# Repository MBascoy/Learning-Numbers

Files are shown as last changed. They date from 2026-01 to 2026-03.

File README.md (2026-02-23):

# Learning Numbers
This is a little educational game for kids (around 3-5 years old) to learn numbers and counting.

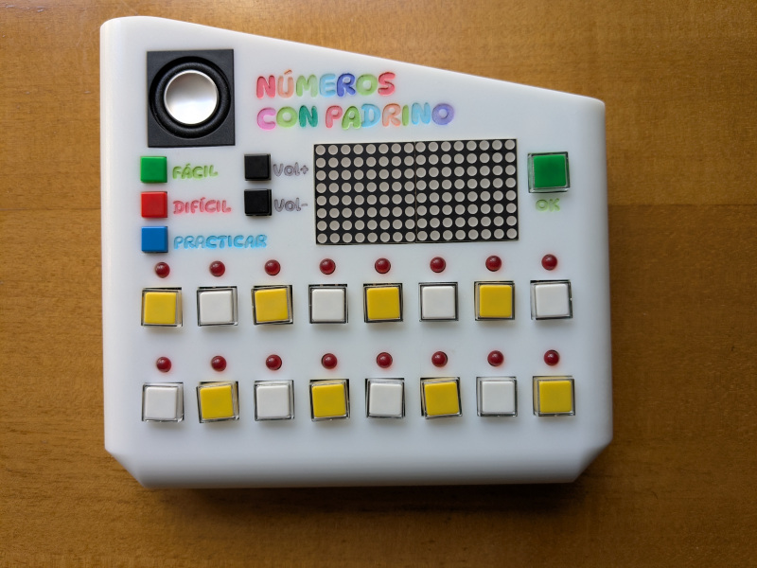
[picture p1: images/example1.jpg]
example1

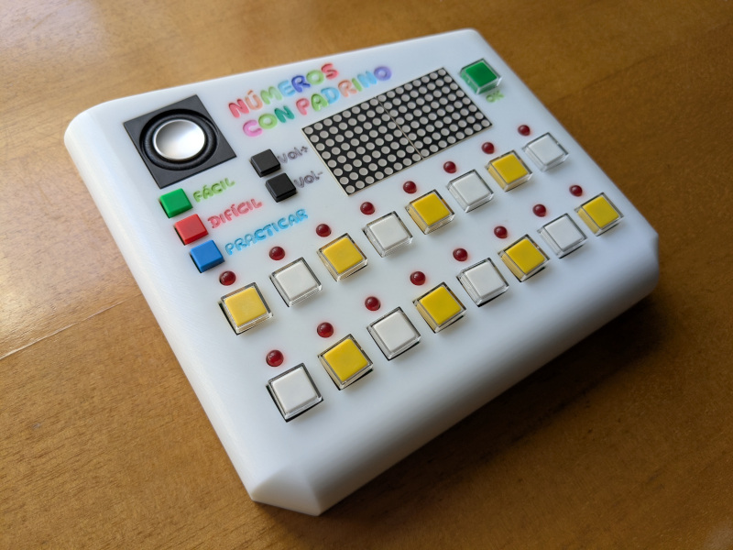
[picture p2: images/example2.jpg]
example2

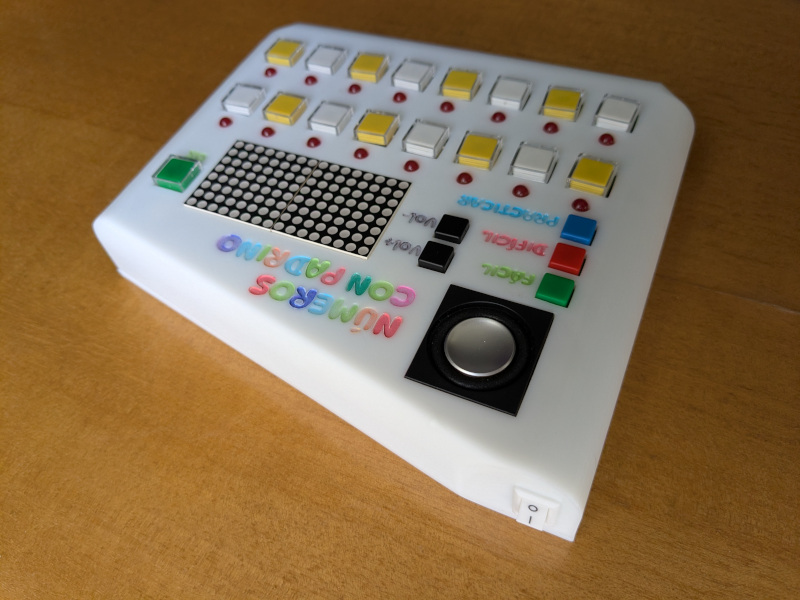
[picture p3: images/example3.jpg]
example3

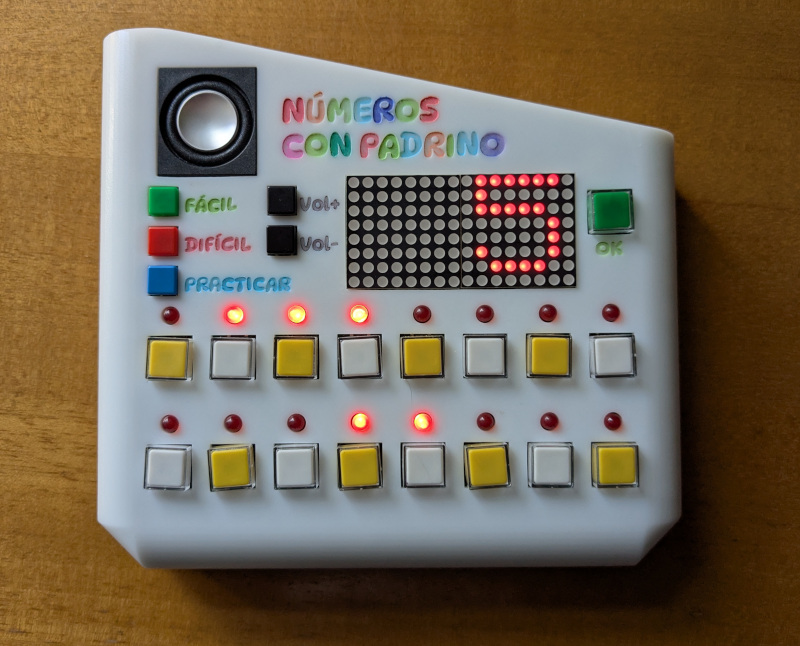
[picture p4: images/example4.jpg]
example4

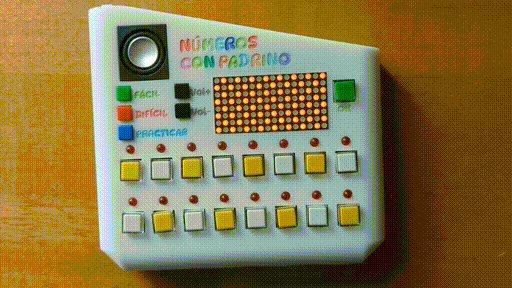
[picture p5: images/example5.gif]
example5


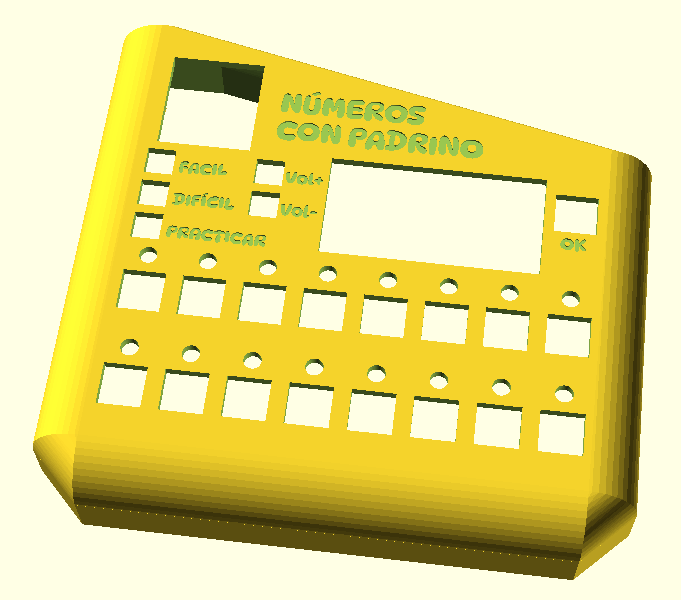
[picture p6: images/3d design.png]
3d design

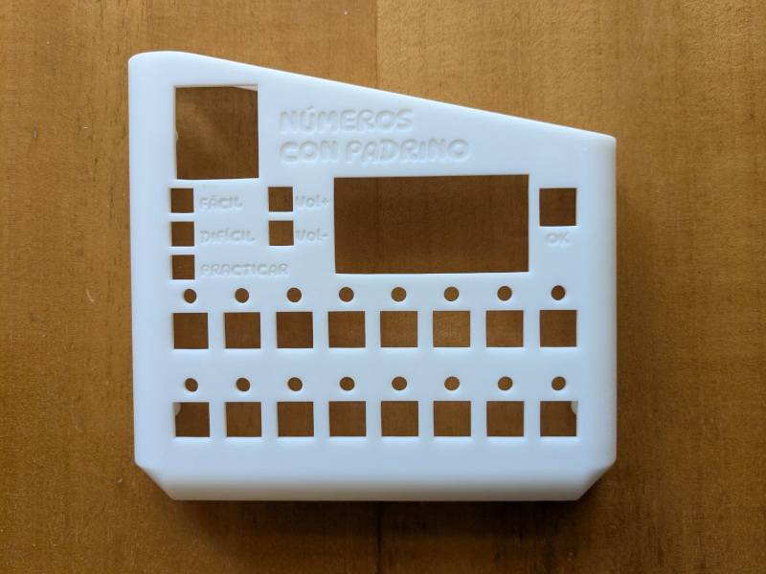
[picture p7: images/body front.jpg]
body front

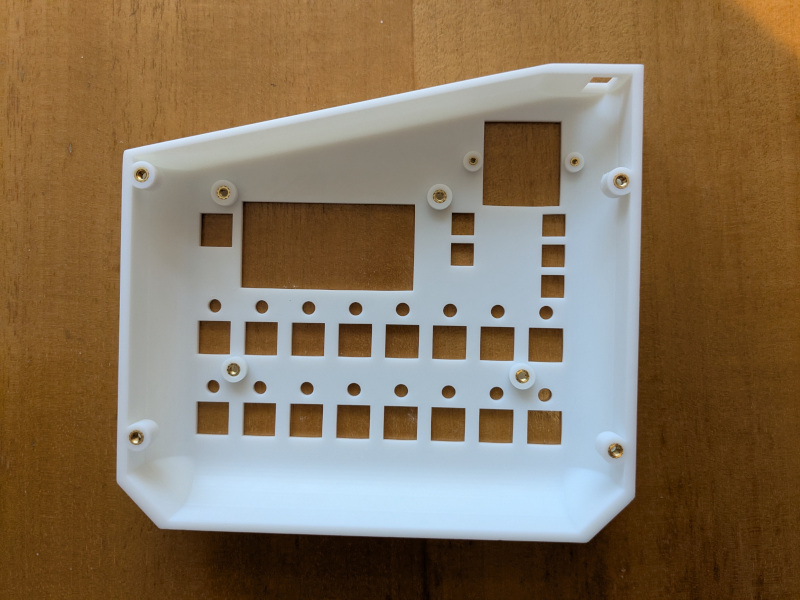
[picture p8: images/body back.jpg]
body back

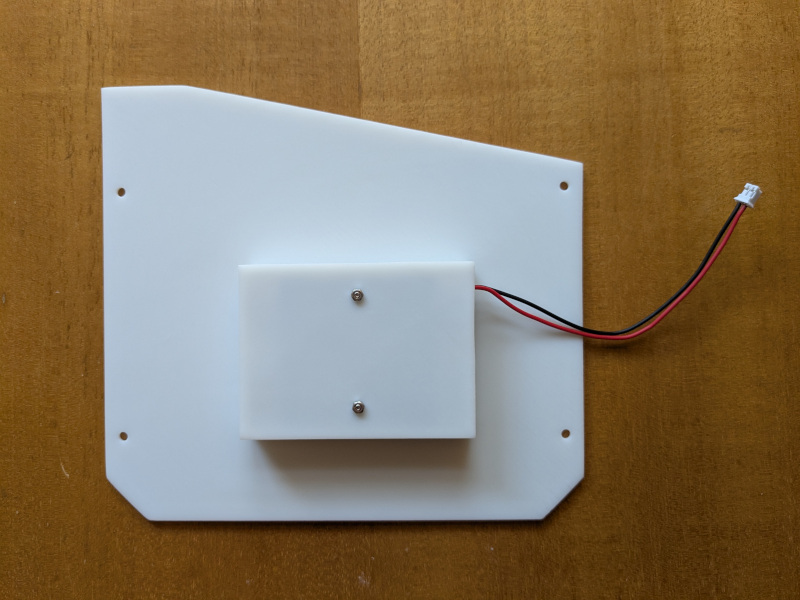
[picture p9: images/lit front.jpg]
lit front

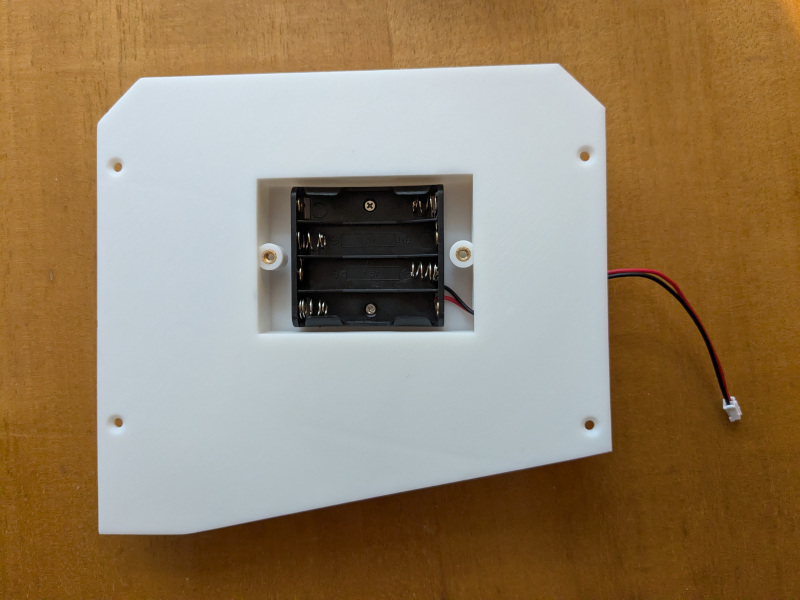
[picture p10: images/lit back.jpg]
lit back


## How to play
The game has 3 modes:
- Easy Mode
- Hard Mode
- Practice Mode

In **Easy Mode** the game displays a random number between 1 and 5, you have to use the two button rows on the bottom to turn on the lights to match the number diplayed (eg: if a 3 is shown you have to press 3 buttons to turn on 3 lights), after that you press "**OK**", if the result is correct you will see a "happy face" and a new number will be shown, if the result is incorrect you will see a "sad face" and you have to correct your answer and try it again.

**Hard Mode** is the same as easy but with numbers between 6 and 16.

In **Practice Mode** the game just show how many lights are on, so you can see which number relates to how many lights are on, (eg: if you turn on 2 lights the display will show you a 2), if you press "**OK**" the game will play an audio of the number that is displayed in the screen.

## How to build
You have to do 3 things:
- Make the 3D design
- Make the PCB (And solder all the components)
- Flash a microcontroller with the code

The components list is the following:

(All the components can be found in Aliexpress)

- 2x matrix led 8x8
- 1x Atmega168pa
- 5x 74HC595 chips
- 2x 74HC165 chips
- 16x 5mm Leds
- 1x 8Mhz crystal oscillator
- 33x 1K resistors
- 16x 10K resistors
- 1x 1Ohm resistor
- 2x 22pf smd capacitors
- 1x 100nf smd capacitor
- 1x 470uf electrolitic capacitor
- 17x SMD Push buttons 12mm
- 5x SMD Push buttons 6mm
- 1x ZIF socket 28pin narrow
- 1x Power switch
- 3x JST connector ph2.0
- 1x battery holder 4x AAA
- 2x Screw M2 inserts (3mm height, 3mm OD)
- 4x M2 Screws
- 2x M2 Nuts
- 6x Screw M3 inserts (5mm height, 5mm OD)
- 4x Screw M3 inserts (3mm height, 5mm OD)
- 8x M3 Screws
- 1x DFPlayer mini
- 1x Speaker 3W 4Ohm PH2.0 terminal

For the **speaker** you need this specific model:

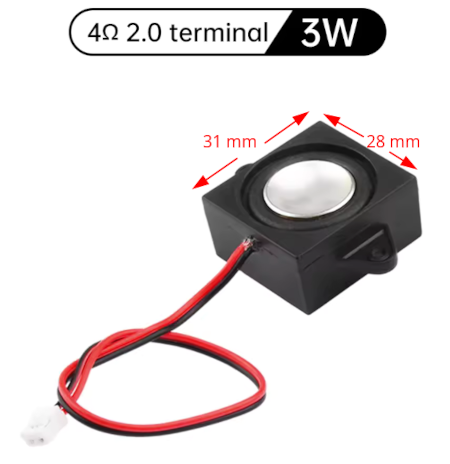
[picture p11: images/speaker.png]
Speaker


For the **power switch** you need this specific model:

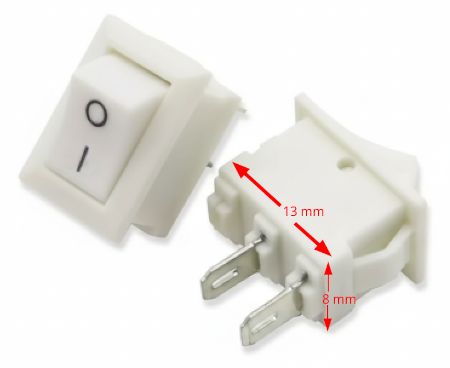
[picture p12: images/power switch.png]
Power switch


You need to add a JST connector (PH 2.0) to the power switch and the battery holder, this is an image of the power switch with the PH 2.0 connector:

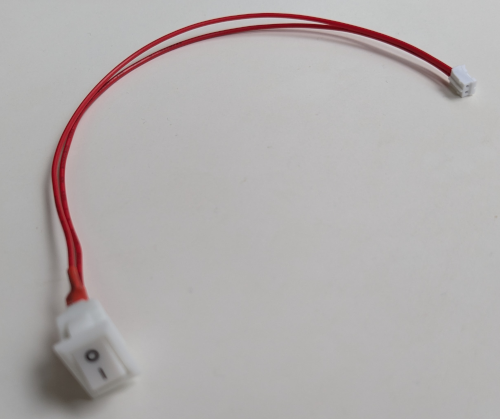
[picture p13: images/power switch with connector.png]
Power switch with connector


### Make the 3D design
Inside **3D design** folder you can find the 3 .stl files ready to print.

If you want to change the text (currently are on spanish), you can do it inside **global_constants.scad** file, after that you have to re-render **learning_numbers.scad** file with **openSCAD** and export the .stl file.

Once you have the 3D design printed you have to put the **screw inserts**:
- 4x M3 inserts (5mm height, 5mm OD) for the lit
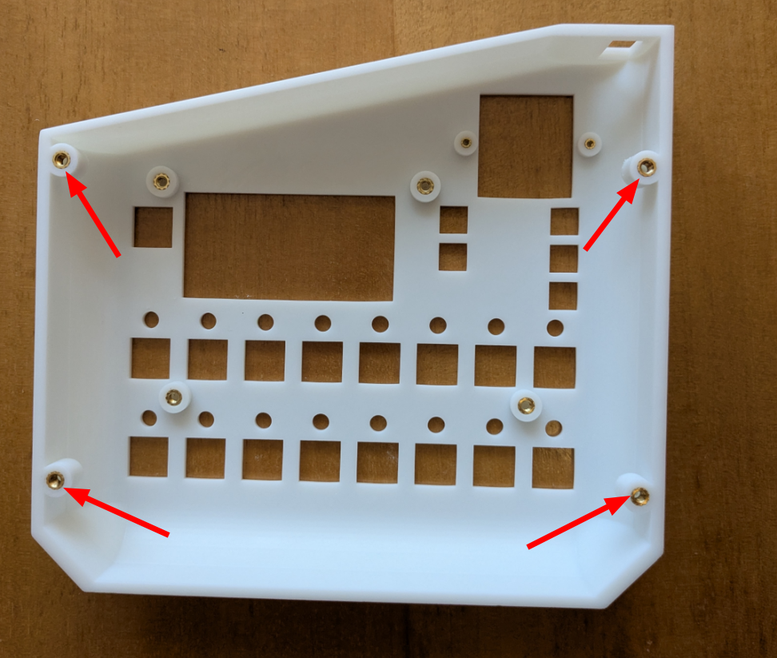
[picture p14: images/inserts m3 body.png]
inserts m3 body

- 2x M3 inserts (5mm height, 5mm OD) for battery lit
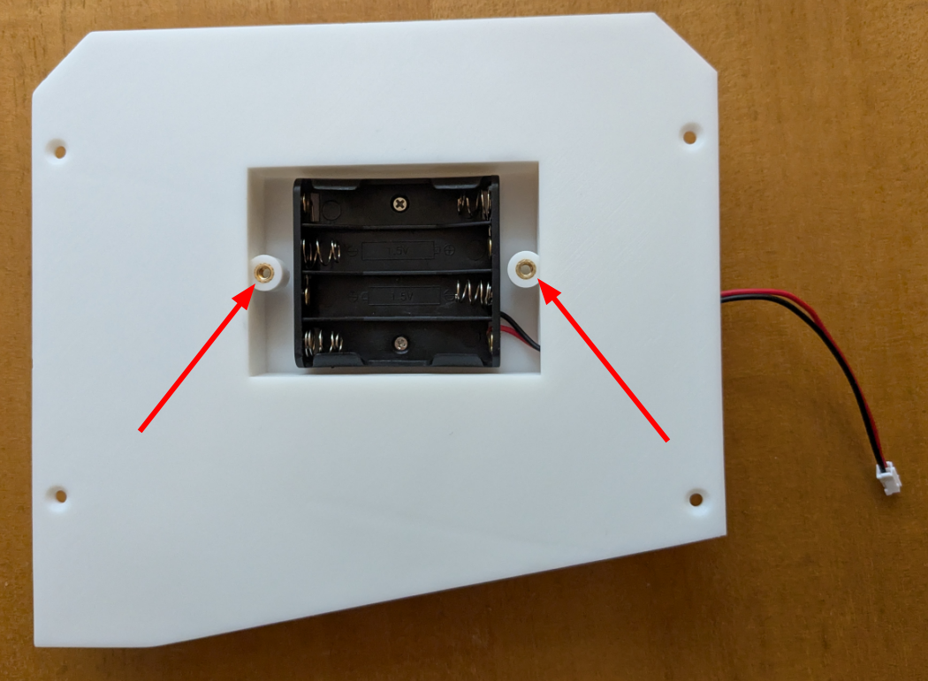
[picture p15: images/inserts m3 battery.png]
inserts m3 battery

- 4x M3 inserts (3mm height, 5mm OD) for the PCB
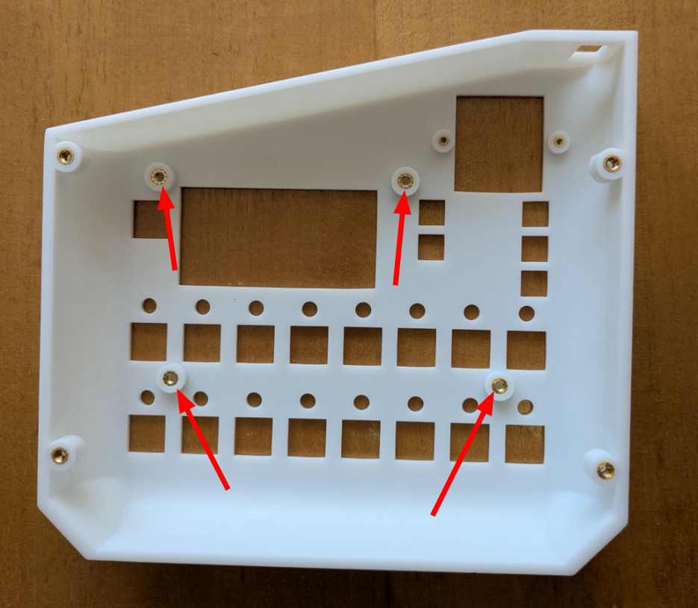
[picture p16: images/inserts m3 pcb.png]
inserts m3 pcb

- 2x M2 inserts (3mm height, 3mm OD) for the speaker
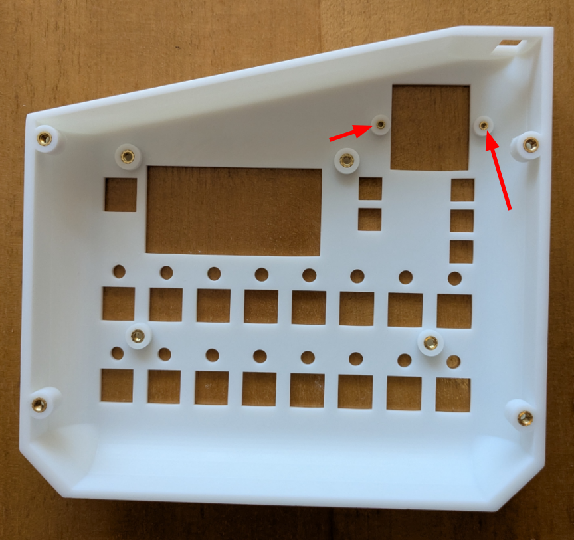
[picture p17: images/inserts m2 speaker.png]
inserts m2 speaker


### Make the PCB
Inside **circuit/Learning_Numbers** folder you can find **Gerber.zip** file which has the PCB ready to be created using a your favorite provider. I've use [jlcpcb.com](https://jlcpcb.com).

When you have the PCB you need to solder the components.

Images of the PCB with no components:

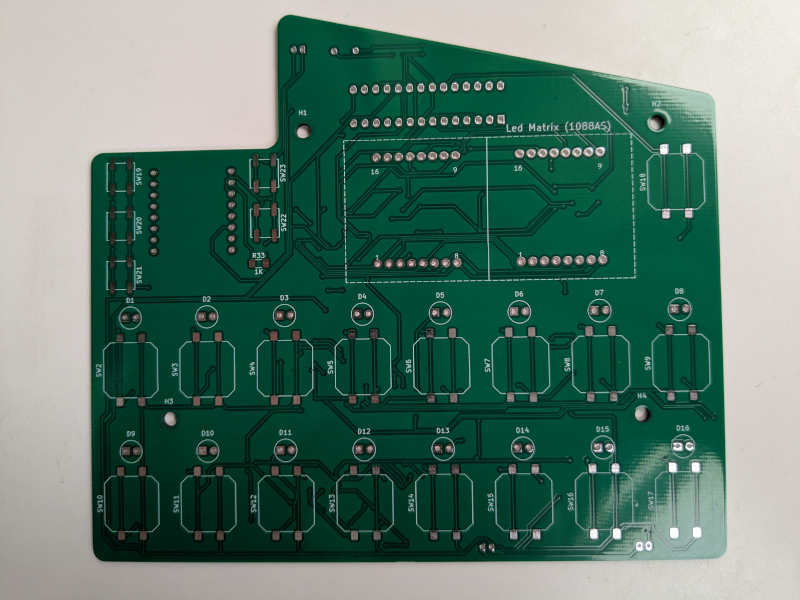
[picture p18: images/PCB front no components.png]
PCB front no components

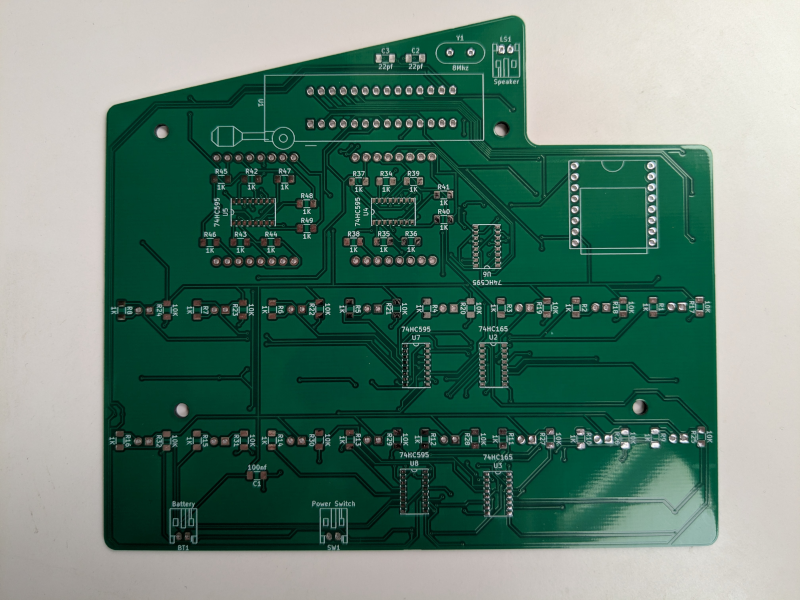
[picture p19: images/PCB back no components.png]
PCB back no components


Image of the final result with all the components:

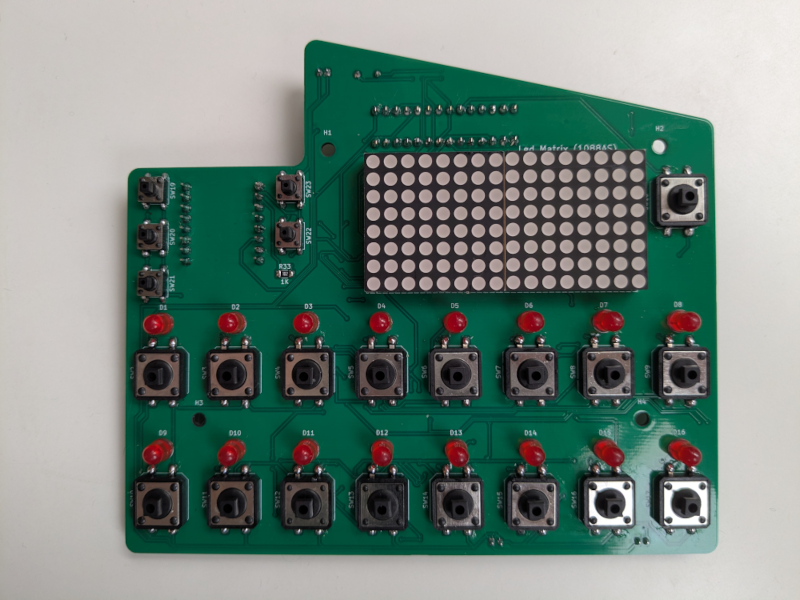
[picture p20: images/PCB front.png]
PCB front with components

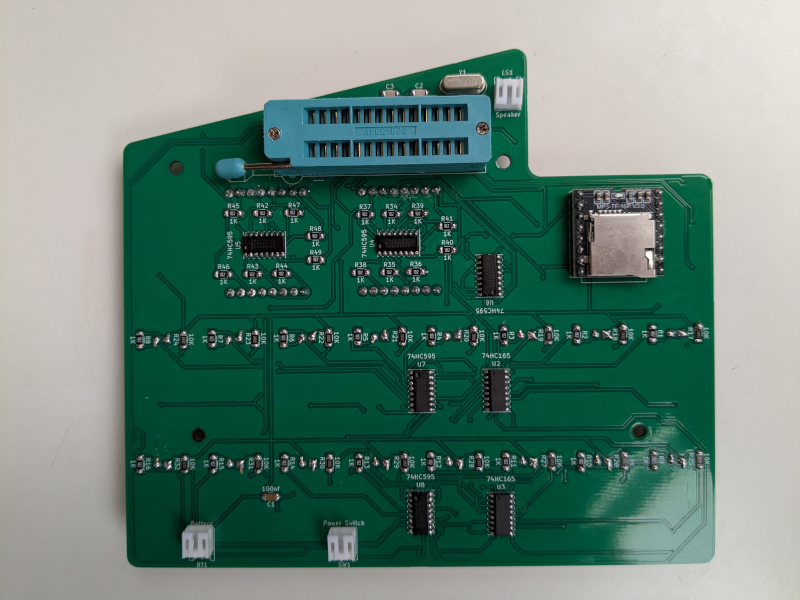
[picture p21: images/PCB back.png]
PCB back with components


### Flash code to microcontroller
The code is ready to flash with a **usbasp** programmer and an **ATMEGA168pa** microcontroller, you only have to go to the **code** folder and run `make flash` command, if you want to use other programmer or microcontroller (an ATMEGA328p for example) you have to update the **Makefile**.

**NOTE:** you have to enable the fuse to use the external crystal, use the following command (for usbasp programmer and atmega168pa microcontroller):
`avrdude -c usbasp -p m168pa -U lfuse:w:0x7F:m`

Once you have flashed the microcontroller just put it inside the ZIF socket on the PCB.

## Audio files
The game uses a **DFPlayer mini** module to play sounds, you need an micro-SD card to put inside the module, the micro-SD card must be formated with **FAT32** file system.

The files inside the micro-SD card must be the followings:

| File name  | Sound |
| --- | --- |
| 001.mp3 | Zero |
| 002.mp3 | One |
| 003.mp3 | Two |
| 004.mp3 | Three |
| 005.mp3 | Four |
| 006.mp3 | Five |
| 007.mp3 | Six |
| 008.mp3 | Seven |
| 009.mp3 | Eight |
| 010.mp3 | Nine |
| 011.mp3 | Ten |
| 012.mp3 | Eleven |
| 013.mp3 | Twelve |
| 014.mp3 | Thriteen |
| 015.mp3 | Fourteen |
| 016.mp3 | Fifteen |
| 017.mp3 | Sixteen |
| 018.mp3 | Title sound |
| 019.mp3 | Easy mode |
| 020.mp3 | Hard mode |
| 021.mp3 | Practice mode |
| 022.mp3 | Success sound |
| 023.mp3 | Fail sound |
| 024.mp3 | Volume Up |
| 025.mp3 | Volume Down |

You can find sample sounds inside the **audio samples** folder.

If you want to add your custom audios the mp3 files should have this parameters (it's not critical, but better for a good performance):

| Parameters | Value |
| --- | --- |
| Format | mp3 |
| Channels | Mono |
| Samples | 44100Hz |
| Speed mode | Constant  |
| Quality | 112kbps |

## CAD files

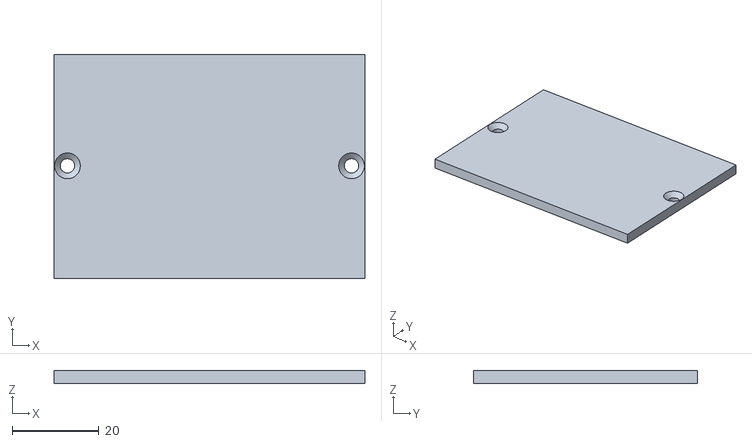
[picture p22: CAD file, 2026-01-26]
3D design/battery_cover.stl
71.7 x 51.7 x 3.00

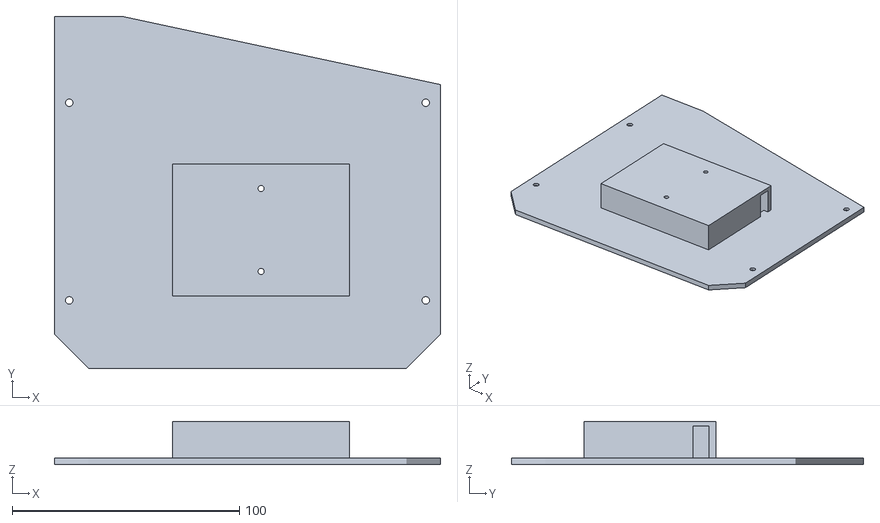
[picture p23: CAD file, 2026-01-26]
3D design/lit.stl
170.0 x 155.0 x 19.0

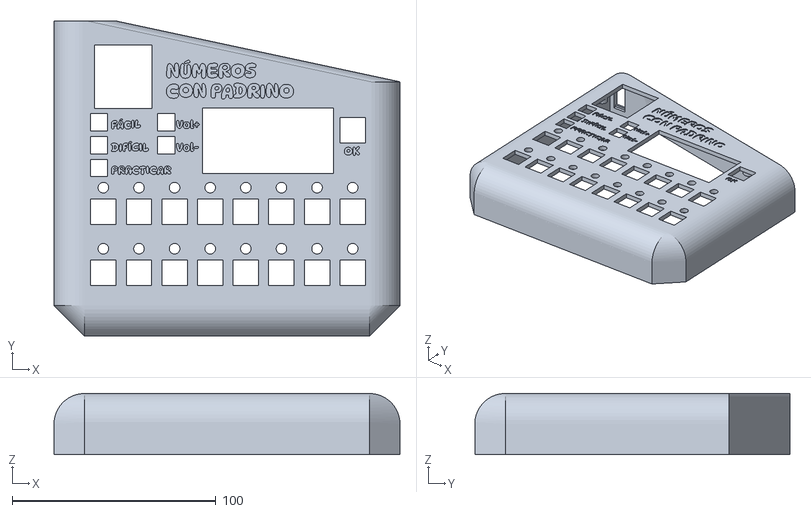
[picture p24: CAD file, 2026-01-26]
3D design/Learning numbers.stl
170.0 x 155.0 x 30.0

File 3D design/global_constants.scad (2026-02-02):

$fn=50;

//Game texts
title_text_1="NÚMEROS";
title_text_2="CON PADRINO";
ok_text="OK";
easy_text="FACIL";
hard_text="DIFÍCIL";
practice_text="PRACTICAR";

volume_plus_text="Vol+";
volume_minus_text="Vol-";


// Body
body_size=140;
body_size_diff=30;
cylinder_radius=15;
body_height=15;

wall_size=4;
wall_size_offset_x= (body_size*(wall_size/100))/2;
wall_size_offset_y= ((body_size+cylinder_radius)*(wall_size/100))/2;

// Anchors
anchor_outer_size=4.5;
anchor_inner_size=2.5;

anchor_inner_size_margin=0.4;

anchor_height=7;
anchor_height_margin=2;

anchor_top_y=-38;
anchor_bottom_y=-125;

body_left_anchor_x = -cylinder_radius + anchor_outer_size + anchor_outer_size - anchor_inner_size;

body_right_anchor_x = body_size + cylinder_radius - (anchor_outer_size + anchor_outer_size - anchor_inner_size);

// Lit
screw_size = 1.65;
screw_top_height = 1.5;
screw_battery_size = 1.35;

lit_height = 3;

lit_battery_x = 40;
lit_battery_y = -120;

lit_battery_x_size = 72;
lit_battery_y_size = 52;

battery_wall = lit_height;

battery_height = 14;

// Speaker
speaker_size=28.2;
speaker_size_y=31.2;
speaker_x=5;
speaker_y=-43;

// Screen
screen_size=32.2;
screen_x=58;
screen_y=-75;

// Power switch
power_switch_size_x=8.7;
power_switch_size_y=14.2;
power_switch_z=-power_switch_size_y/1.5;

// Buttons
button_size=12.5;
button_x_margin=5;
button_starting_x=3;

button_x_placement=button_size + button_x_margin;
button_y_placement=-100;
button_y_second_row=30;

confirm_button_x=body_size - button_size-2;
confirm_button_y=-60;

// Leds
led_size=2.6;
led_height=10;

// Text
text_depth=0.6;

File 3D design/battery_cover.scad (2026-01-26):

include<global_constants.scad>;

cover_margin = 0.3;

difference(){
    translate([cover_margin/2,0,0]) cube([lit_battery_x_size - cover_margin,  lit_battery_y_size - cover_margin, lit_height]);
    
    // Left hole
    base_hole(anchor_outer_size - (anchor_inner_size/2));
    
    // Right hole
    base_hole(lit_battery_x_size - anchor_outer_size + (anchor_inner_size/2));

}

module base_hole(x){
    translate([x, lit_battery_y_size / 2, 0]) cylinder(lit_height, screw_size, screw_size);
    
    translate([x, lit_battery_y_size / 2, lit_height-screw_top_height]) cylinder(screw_top_height, screw_size, screw_size*1.8);
}

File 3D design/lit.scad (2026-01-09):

include<global_constants.scad>;

use<body/body_bottom.scad>;
use<lit/lit_holes.scad>;
use<lit/lit_battery_box.scad>;
use<lit/battery_anchors.scad>;


difference(){
    hull() linear_extrude(height = lit_height) projection() body_bottom();
  
    lit_holes();
    
    lit_battery_hole();
}

lit_battery_box();

anchor_battery();

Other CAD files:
3D design/main.scad
3D design/anchors/anchor_body.scad
3D design/anchors/anchor_pcb.scad
3D design/anchors/anchor_speaker.scad
3D design/anchors/anchor_speaker_old.scad
3D design/body/body_bottom.scad
3D design/body/body_text.scad
3D design/body/body_top.scad
3D design/body/holes/buttons_counting.scad
3D design/body/holes/menu.scad
3D design/body/holes/power_switch.scad
3D design/body/holes/screen.scad
3D design/body/holes/speaker.scad
3D design/lit/battery_anchors.scad
3D design/lit/lit_battery_box.scad
3D design/lit/lit_holes.scad

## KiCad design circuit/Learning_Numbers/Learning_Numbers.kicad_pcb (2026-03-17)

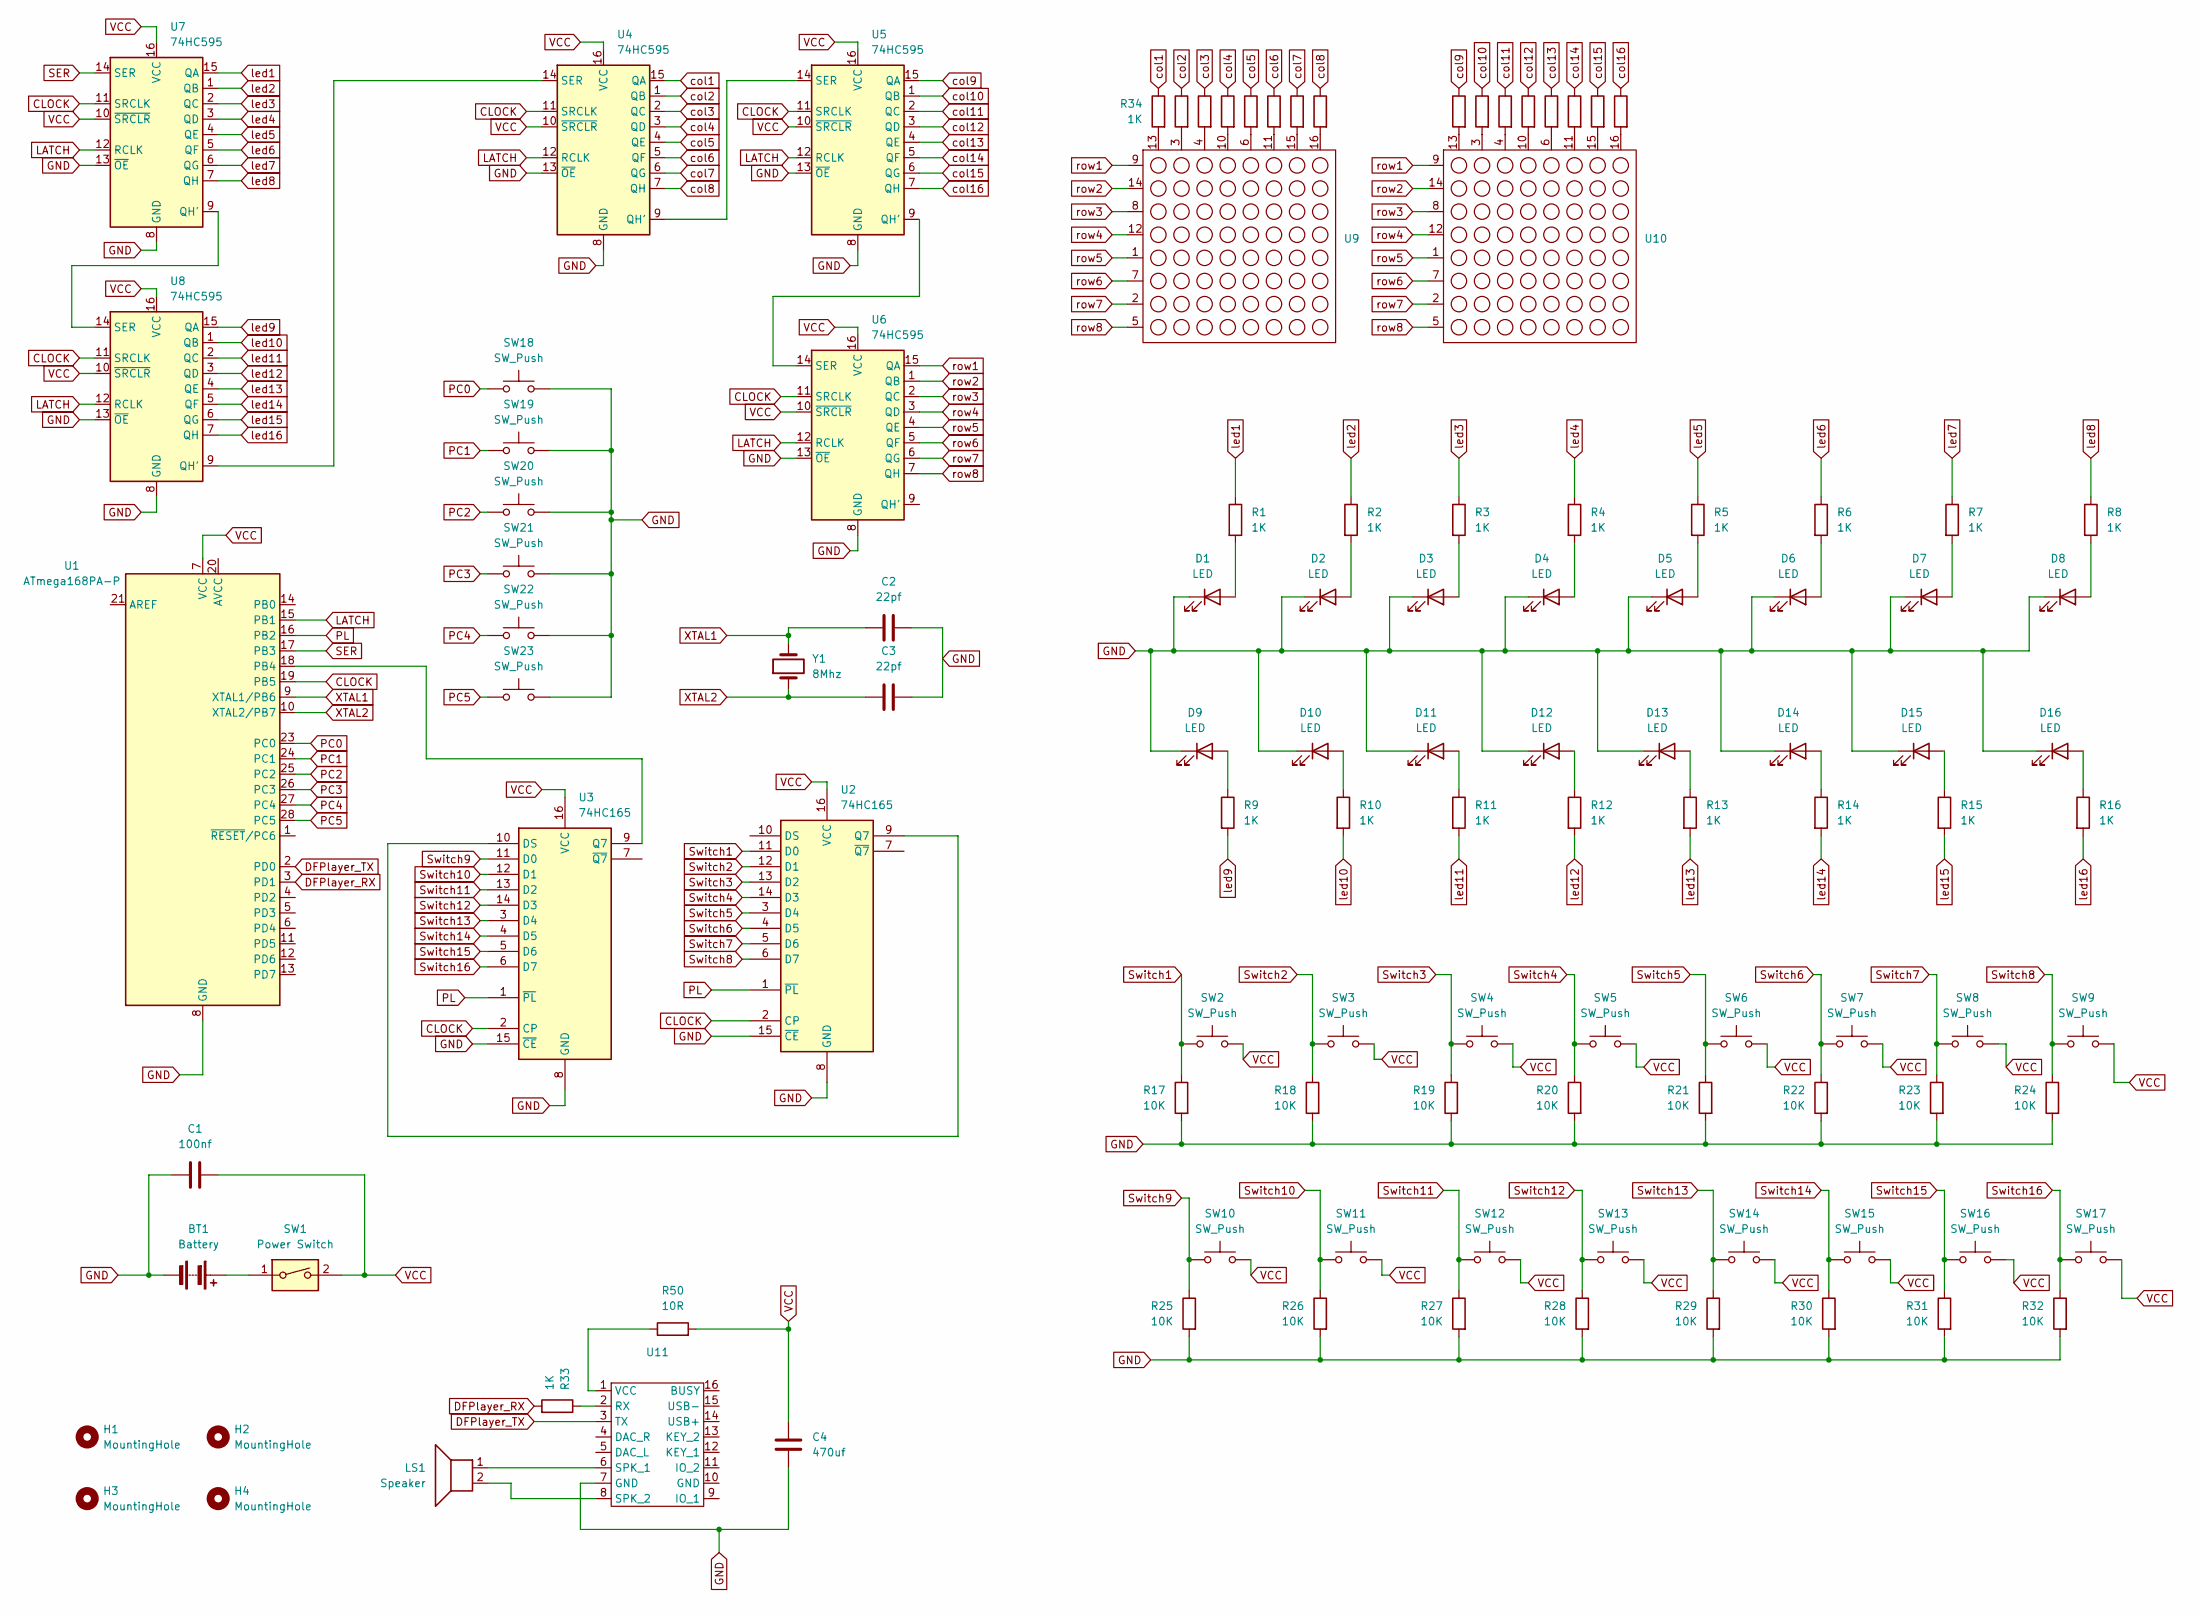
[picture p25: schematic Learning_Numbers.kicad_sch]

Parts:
BT1: Battery; JST_PH_S2B-PH-K_1x02_P2.00mm_Horizontal
C1: 100nf; C_1206_3216Metric_Pad1.33x1.80mm_HandSolder
C2, C3: 22pf; C_1206_3216Metric_Pad1.33x1.80mm_HandSolder
C4: 470uf; C_Elec_8x10.2
D1, D2, D3, D4, D5, D6, D7, D8, D9, D10, D11, D12, D13, D14, D15, D16: LED; LED_D5.0mm
H1, H2, H3, H4: MountingHole; MountingHole_3.2mm_M3
LS1: Speaker; JST_PH_S2B-PH-K_1x02_P2.00mm_Horizontal
R1, R2, R3, R4, R5, R6, R7, R8, R9, R10, R11, R12, R13, R14, R15, R16, R33, R34, R35, R36, R37, R38, R39, R40, R41, R42, R43, R44, R45, R46, R47, R48, R49: 1K; R_1206_3216Metric_Pad1.30x1.75mm_HandSolder
R17, R18, R19, R20, R21, R22, R23, R24, R25, R26, R27, R28, R29, R30, R31, R32: 10K; R_1206_3216Metric_Pad1.30x1.75mm_HandSolder
R50: 10R; R_1206_3216Metric_Pad1.30x1.75mm_HandSolder
SW1: Power Switch; JST_PH_S2B-PH-K_1x02_P2.00mm_Horizontal
SW2, SW3, SW4, SW5, SW6, SW7, SW8, SW9, SW10, SW11, SW12, SW13, SW14, SW15, SW16, SW17: SW_Push; SW_Push_1P1T_NO_CK_PTS125Sx73SMTR
SW18: SW_Push; SW_Push_1P1T_NO_CK_PTS125Sx43SMTR
SW19, SW20, SW21, SW22, SW23: SW_Push; SW_Push_1P1T_NO_CK_KSC7xxJ
U1: ATmega168PA-P; ZIF_Socket-28_W7.62
U2, U3: 74HC165; 74HC165D
U4, U5, U6, U7, U8: 74HC595; 74HC595D
U9, U10: 1088AS_Led_3mm_size_32mm
U11: DFPlayer_mini
Y1: 8Mhz; Crystal_HC49-4H_Vertical

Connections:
CLOCK: U1.19 (PB5), U2.2 (CP), U3.2 (CP), U4.11 (SRCLK), U5.11 (SRCLK), U6.11 (SRCLK), U7.11 (SRCLK), U8.11 (SRCLK)
DFPlayer_RX: R33.2, U1.3 (PD1)
DFPlayer_TX: U1.2 (PD0), U11.3 (TX)
GND: BT1.2 (-), C1.2, C2.2, C3.2, C4.2, D1.1 (K), D2.1 (K), D3.1 (K), D4.1 (K), D5.1 (K), D6.1 (K), D7.1 (K), D8.1 (K), D9.1 (K), D10.1 (K), D11.1 (K), D12.1 (K), D13.1 (K), D14.1 (K), D15.1 (K), D16.1 (K), R17.2, R18.2, R19.2, R20.2, R21.2, R22.2, R23.2, R24.2, R25.2, R26.2, R27.2, R28.2, R29.2, R30.2, R31.2, R32.2, SW18.2, SW19.2, SW20.2, SW21.2, SW22.2, SW23.2, U1.8 (GND), U1.22 (GND), U2.8 (GND), U2.15 (~CE), U3.8 (GND), U3.15 (~CE), U4.8 (GND), U4.13 (~OE), U5.8 (GND), U5.13 (~OE), U6.8 (GND), U6.13 (~OE), U7.8 (GND), U7.13 (~OE), U8.8 (GND), U8.13 (~OE), U11.7 (GND)
LATCH: U1.15 (PB1), U4.12 (RCLK), U5.12 (RCLK), U6.12 (RCLK), U7.12 (RCLK), U8.12 (RCLK)
unnamed: BT1.1 (+), SW1.1
unnamed: D1.2 (A), R1.2
unnamed: D2.2 (A), R2.2
unnamed: D3.2 (A), R3.2
unnamed: D4.2 (A), R4.2
unnamed: D5.2 (A), R5.2
unnamed: D6.2 (A), R6.2
unnamed: D7.2 (A), R7.2
unnamed: D8.2 (A), R8.2
unnamed: D9.2 (A), R9.1
unnamed: D10.2 (A), R10.1
unnamed: D11.2 (A), R11.1
unnamed: D12.2 (A), R12.1
unnamed: D13.2 (A), R13.1
unnamed: D14.2 (A), R14.1
unnamed: D15.2 (A), R15.1
unnamed: D16.2 (A), R16.1
unnamed: R34.2, U9.13
unnamed: R35.2, U9.3
unnamed: R36.2, U9.4
unnamed: R37.2, U9.10
unnamed: R38.2, U9.6
unnamed: R39.2, U9.11
unnamed: R40.2, U9.15
unnamed: R41.2, U9.16
unnamed: R42.2, U10.13
unnamed: R43.2, U10.3
unnamed: R44.2, U10.4
unnamed: R45.2, U10.10
unnamed: R46.2, U10.6
unnamed: R47.2, U10.11
unnamed: R48.2, U10.15
unnamed: R49.2, U10.16
unnamed: U1.18 (PB4), U3.9 (Q7)
unnamed: U2.9 (Q7), U3.10 (DS)
unnamed: U4.9 (QH'), U5.14 (SER)
unnamed: U4.14 (SER), U8.9 (QH')
unnamed: U5.9 (QH'), U6.14 (SER)
unnamed: U7.9 (QH'), U8.14 (SER)
unnamed: R33.1, U11.2 (RX)
unnamed: LS1.1, U11.6 (SPK_1)
unnamed: LS1.2, U11.8 (SPK_2)
unnamed: R50.1, U11.1 (VCC)
PC0: SW18.1, U1.23 (PC0)
PC1: SW19.1, U1.24 (PC1)
PC2: SW20.1, U1.25 (PC2)
PC3: SW21.1, U1.26 (PC3)
PC4: SW22.1, U1.27 (PC4)
PC5: SW23.1, U1.28 (PC5)
PL: U1.16 (PB2), U2.1 (~PL), U3.1 (~PL)
SER: U1.17 (PB3), U7.14 (SER)
Switch1: R17.1, SW2.1, U2.11 (D0)
Switch2: R18.1, SW3.1, U2.12 (D1)
Switch3: R19.1, SW4.1, U2.13 (D2)
Switch4: R20.1, SW5.1, U2.14 (D3)
Switch5: R21.1, SW6.1, U2.3 (D4)
Switch6: R22.1, SW7.1, U2.4 (D5)
Switch7: R23.1, SW8.1, U2.5 (D6)
Switch8: R24.1, SW9.1, U2.6 (D7)
Switch9: R25.1, SW10.1, U3.11 (D0)
Switch10: R26.1, SW11.1, U3.12 (D1)
Switch11: R27.1, SW12.1, U3.13 (D2)
Switch12: R28.1, SW13.1, U3.14 (D3)
Switch13: R29.1, SW14.1, U3.3 (D4)
Switch14: R30.1, SW15.1, U3.4 (D5)
Switch15: R31.1, SW16.1, U3.5 (D6)
Switch16: R32.1, SW17.1, U3.6 (D7)
VCC: C1.1, C4.1, R50.2, SW1.2, SW2.2, SW3.2, SW4.2, SW5.2, SW6.2, SW7.2, SW8.2, SW9.2, SW10.2, SW11.2, SW12.2, SW13.2, SW14.2, SW15.2, SW16.2, SW17.2, U1.7 (VCC), U2.16 (VCC), U3.16 (VCC), U4.10 (~SRCLR), U4.16 (VCC), U5.10 (~SRCLR), U5.16 (VCC), U6.10 (~SRCLR), U6.16 (VCC), U7.10 (~SRCLR), U7.16 (VCC), U8.10 (~SRCLR), U8.16 (VCC)
XTAL1: C2.1, U1.9 (XTAL1/PB6), Y1.2
XTAL2: C3.1, U1.10 (XTAL2/PB7), Y1.1
col1: R34.1, U4.15 (QA)
col2: R35.1, U4.1 (QB)
col3: R36.1, U4.2 (QC)
col4: R37.1, U4.3 (QD)
col5: R38.1, U4.4 (QE)
col6: R39.1, U4.5 (QF)
col7: R40.1, U4.6 (QG)
col8: R41.1, U4.7 (QH)
col9: R42.1, U5.15 (QA)
col10: R43.1, U5.1 (QB)
col11: R44.1, U5.2 (QC)
col12: R45.1, U5.3 (QD)
col13: R46.1, U5.4 (QE)
col14: R47.1, U5.5 (QF)
col15: R48.1, U5.6 (QG)
col16: R49.1, U5.7 (QH)
led1: R1.1, U7.15 (QA)
led2: R2.1, U7.1 (QB)
led3: R3.1, U7.2 (QC)
led4: R4.1, U7.3 (QD)
led5: R5.1, U7.4 (QE)
led6: R6.1, U7.5 (QF)
led7: R7.1, U7.6 (QG)
led8: R8.1, U7.7 (QH)
led9: R9.2, U8.15 (QA)
led10: R10.2, U8.1 (QB)
led11: R11.2, U8.2 (QC)
led12: R12.2, U8.3 (QD)
led13: R13.2, U8.4 (QE)
led14: R14.2, U8.5 (QF)
led15: R15.2, U8.6 (QG)
led16: R16.2, U8.7 (QH)
row1: U6.15 (QA), U9.9, U10.9
row2: U6.1 (QB), U9.14, U10.14
row3: U6.2 (QC), U9.8, U10.8
row4: U6.3 (QD), U9.12, U10.12
row5: U6.4 (QE), U9.1, U10.1
row6: U6.5 (QF), U9.7, U10.7
row7: U6.6 (QG), U9.2, U10.2
row8: U6.7 (QH), U9.5, U10.5

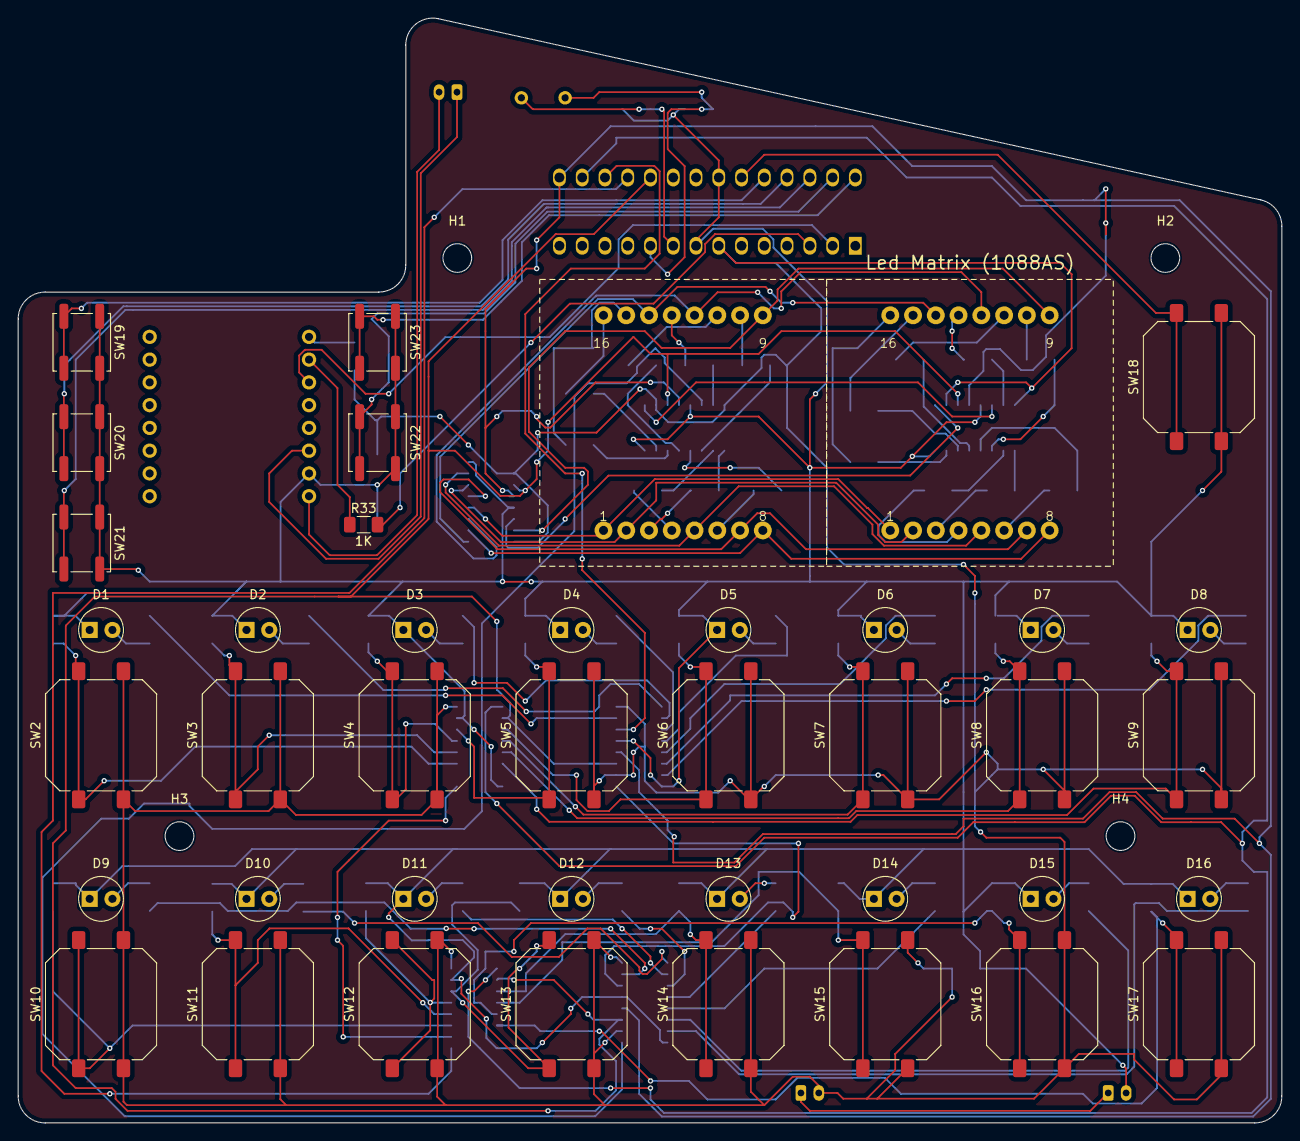
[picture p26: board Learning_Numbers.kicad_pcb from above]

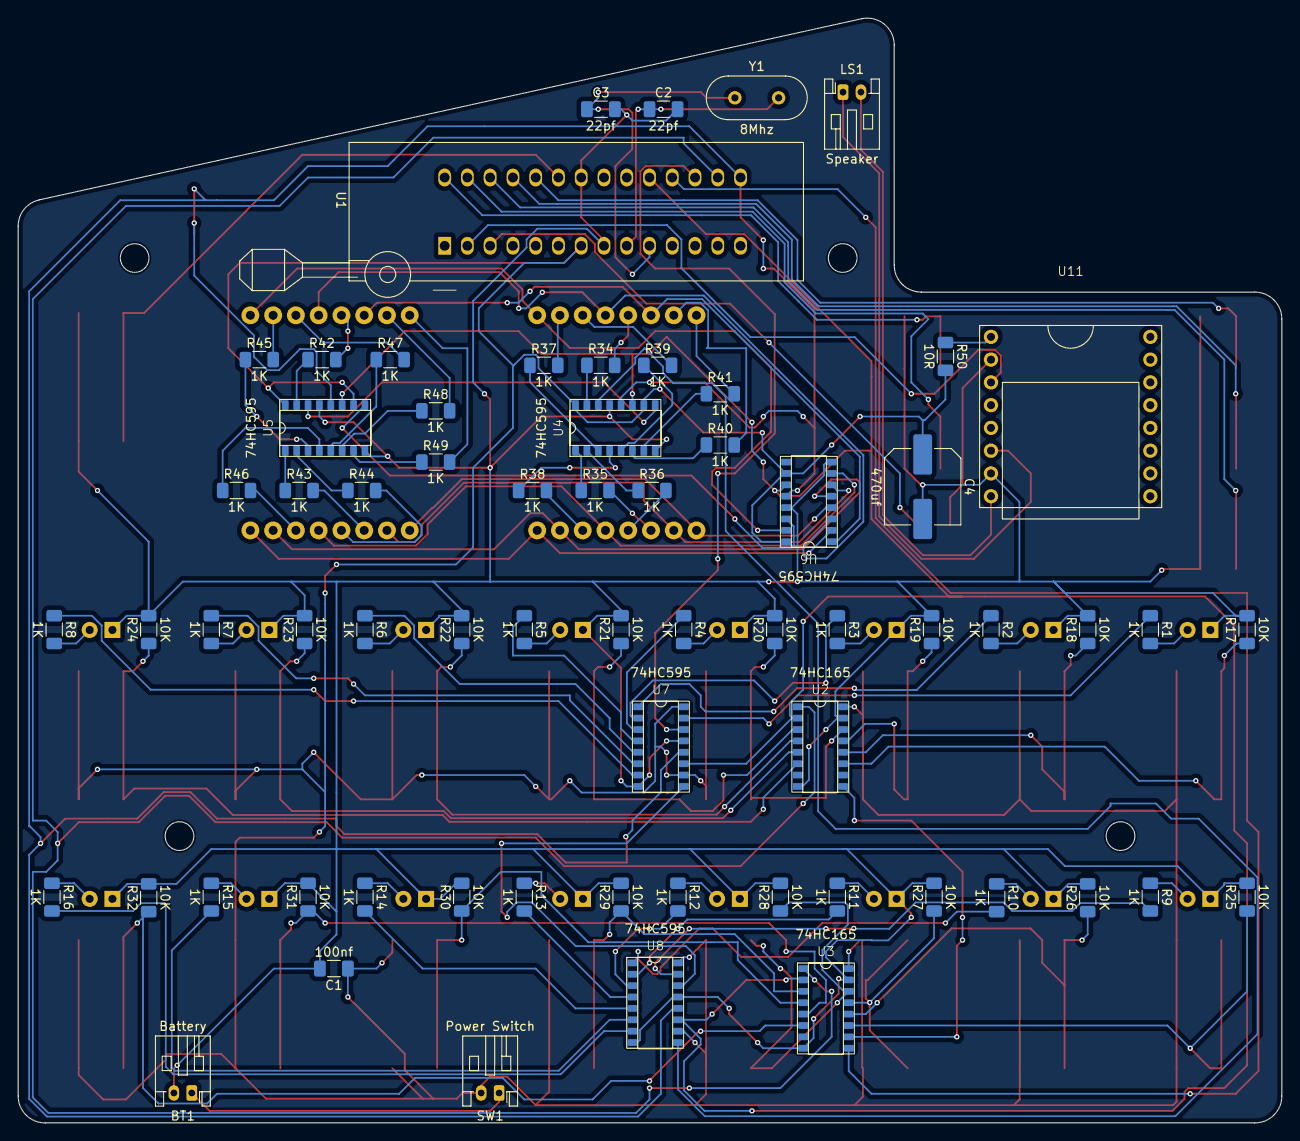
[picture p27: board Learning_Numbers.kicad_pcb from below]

Board: 2 copper layers, 141.0 x 123.3 mm, 111 parts (66 on the bottom side), 115 nets.

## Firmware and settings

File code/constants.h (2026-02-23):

// Definiciones de pines
#define DDR_SPI  DDRB
#define DD_MISO  PB4
#define DD_SCK   PB5
#define DD_MOSI    PB3 // El pin SS debe ser salida para modo Master
#define PL_PIN   PB2  // Pin para Parallel Load
#define LATCH_PIN   PB1  // Pin para Parallel Load

#define ANIMATION_DELAY 90 // Miliseconds for animation steps
#define ANIMATION_DURATION 1000 // How much Animation lasts
#define DEBOUNCE_DURATION 170 // iterations for button debounce
#define RESULT_DURATION 1500 // Miliseconds to show result before next level

#define START_AUDIO 18 // Track to play when starting a game
#define EASY_MODE_AUDIO 19
#define HARD_MODE_AUDIO 20
#define PRACTICE_MODE_AUDIO 21
#define SUCCESS_AUDIO 22 // Track to play on success
#define FAILURE_AUDIO 23 // Track to play on failure
#define VOLUME_UP_AUDIO 24 // Track to play on failure
#define VOLUME_DOWN_AUDIO 25 // Track to play on failure

#define DEFAULT_VOLUME 15 // Default volume level (0-30)

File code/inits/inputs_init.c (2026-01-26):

#include <avr/io.h>

void inputs_init(){
    //set PC0, PC1, PC2, PC3 as inputs
    DDRC &= ~((1 << PC0) | (1 << PC1) | (1 << PC2) | (1 << PC3)) | (1 << PC4) | (1 << PC5);

    // TEMPORAL !!!!!!!!!!!!
    DDRD = 0b00000011;

    //pull-up resistors
    PORTC |= (1 << PC0) | (1 << PC1) | (1 << PC2) | (1 << PC3) | (1 << PC4) | (1 << PC5);

    PCICR |= (1 << PCIE1);
    PCMSK1 |= (1 << PC0) | (1 << PC1) | (1 << PC2) | (1 << PC3) | (1 << PC4) | (1 << PC5);
}

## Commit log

2025-12-18 Add 3d design
    [Learning numbers.stl, anchor_body.scad, anchor_speaker.scad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]
2025-12-19 add pcb anchors and power switch hole
    [anchor_pcb.scad, body_bottom.scad, buttons_counting.scad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]
2025-12-19 update variables
    [Learning numbers.stl, anchor_pcb.scad, global_constants.scad]
2025-12-25 add simulation and basic code
    [Learning numbers.stl, anchor_body.scad, anchor_pcb.scad]
2026-01-04 update 3D design
    [Learning numbers.stl, anchor_speaker.scad, anchor_speaker_old.scad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]
2026-01-06 update 3D design parameters
    [Learning numbers.stl, anchor_speaker.scad, global_constants.scad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]
2026-01-06 add Kicad circuit
    [Learning_Numbers.kicad_pcb, Learning_Numbers.kicad_sch]
2026-01-07 finish circuit pathing
    [Learning_Numbers-B_Cu.gbr, Learning_Numbers-B_Mask.gbr, Learning_Numbers-B_Paste.gbr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]
2026-01-07 add crystal to circuit
    [Learning_Numbers.kicad_pcb, Learning_Numbers.kicad_sch]
2026-01-08 add battery case to 3d design
    [Learning_Numbers.kicad_pcb, anchor_body.scad, anchor_pcb.scad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]
2026-01-09 update battery box
    [global_constants.scad, lit.scad, lit_battery_box.scad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]
2026-01-09 add battery screws
    [lit.stl, lit_battery_box.scad]
2026-01-09 add battery anchors
    [battery_anchors.scad, lit.scad, lit_holes.scad]
2026-01-09 3D design finish battery cover
    [Learning numbers.stl, battery_cover.scad, battery_cover.stl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]
2026-01-10 add body text
    [body_text.scad, body_top.scad]
2026-01-12 update pcb silk layer
    [Learning numbers.stl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]
2026-01-24 update 3D design and circuit
    [Learning numbers.stl, body_text.scad, body_top.scad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]
2026-01-24 update code, switch inputs, boot sequence and sounds
2026-01-26 add final adjust to 3d design and code
    [Learning numbers.stl, battery_cover.scad, battery_cover.stl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]
2026-02-02 add README.md and audio samples
2026-02-02 Add new images to README, update 3d design text variables
    [body_text.scad, global_constants.scad, menu.scad]
2026-02-16 update circuit add capacitor DFPlayer and change speaker conections
    [Learning_Numbers.kicad_pcb, Learning_Numbers.kicad_sch]
2026-02-21 add test leds and adjust audio volume
2026-02-23 Update circuit to add DFPlayer 10 ohm resistor
    [Learning_Numbers.kicad_pcb, Learning_Numbers.kicad_sch]
2026-02-23 Update code to change max volume and add initial test for leds
2026-03-17 Update gerber files
    [Learning_Numbers-B_Cu.gbr, Learning_Numbers-B_Mask.gbr, Learning_Numbers-B_Paste.gbr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]
